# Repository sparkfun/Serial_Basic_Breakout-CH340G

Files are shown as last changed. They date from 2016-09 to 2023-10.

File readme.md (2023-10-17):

SparkFun Serial Basic Breakout - CH340G
========================================

SparkFun Serial Basic Breakout - CH340G

[*SparkFun Serial Basic Breakout - CH340G (DEV-14050)*](https://www.sparkfun.com/products/14050)

This is a CH340G based board that converts USB to Serial. 
It follows the standard Arduino pin out so this can be used to program the Pro and Pro Mini line of Arduinos. 
It can also be used as a general serial device for debugging (such as with a GPS module).

Board is default 3.3V output and 3.3V serial signals but cutting the trace on the back of the board and 
soldering a jumper to 5V changes the VCC pin to output 5V and changes serial comm signals to 5V.

Repository Contents
-------------------

* **/Hardware** - Eagle design files (.brd, .sch)
* **/Production** - Production panel files (.brd)

Documentation
--------------
* **[Hookup Guide](https://learn.sparkfun.com/tutorials/serial-basic-hookup-guide)** - Basic hookup guide
* **[How to Install CH340 Drivers](https://www.sparkfun.com/ch340)** - Drivers if you need
* **[SparkFun Fritzing repo](https://github.com/sparkfun/Fritzing_Parts/blob/main/products/14050_sfe_serial_basic_breakout_ch340g.fzpz)** - Fritzing diagrams for SparkFun products.
* **[SparkFun 3D Model repo](https://github.com/sparkfun/3D_Models)** - 3D models of SparkFun products. 
* **[SparkFun Graphical Datasheets](https://github.com/sparkfun/Graphical_Datasheets)** -Graphical Datasheets for various SparkFun products.

License Information
-------------------

This product is _**open source**_! 

Please review the LICENSE.md file for license information. 

If you have any questions or concerns on licensing, please contact techsupport@sparkfun.com.

Distributed as-is; no warranty is given.

- Your friends at SparkFun.

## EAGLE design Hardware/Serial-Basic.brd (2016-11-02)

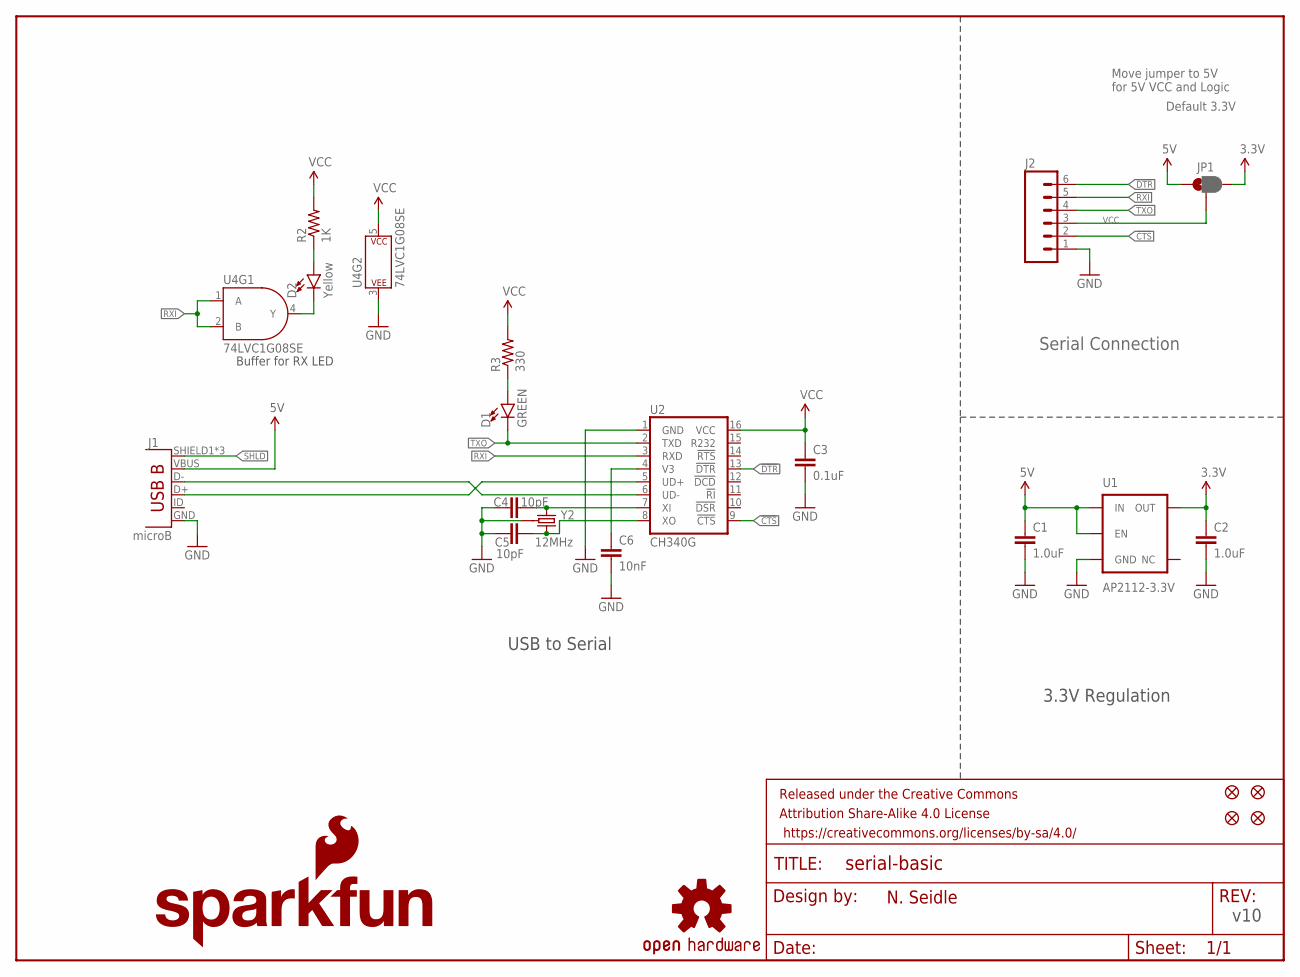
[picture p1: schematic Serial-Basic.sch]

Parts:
C1, C2: 1.0uF; 0603-CAP
C3: 0.1uF; 0603-CAP
C4, C5: 10pF; 0603-CAP
C6: 10nF; 0603-CAP
D1: GREEN; LED-0603
D2: Yellow; LED-0603
FRAME1: FRAME-LETTER; CREATIVE_COMMONS
J1: microB; USB-B-MICRO-SMD_V03
J2: M06SMD-FEMALE-V2; 1X06-SMD-FEMALE-V2
JP1: JUMPER-PAD-3-2OF3_NC_BY_PASTE; PAD-JUMPER-3-2OF3_NC_BY_PASTE_YES_SILK_FULL_BOX
JP3, JP4, JP5, JP6: FIDUCIAL1X2; FIDUCIAL-1X2
LOGO1: OSHW-LOGOS; OSHW-LOGO-S
LOGO2: SFE_LOGO_FLAME.1_INCH; SFE_LOGO_FLAME_.1
LOGO3: SFE_LOGO_NAME.1_INCH; SFE_LOGO_NAME_.1
R2: 1K; 0603-RES
R3: 330; 0603-RES
U1: AP2112-3.3V; SOT23-5
U2: CH340G; SO016
U4: 74LVC1G08SE; SOT353
Y2: 12MHz; CRYSTAL-SMD-3.2X2.5

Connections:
3.3V: C2.1, JP1.3, U1.5 (OUT)
5V: C1.1, J1.VBUS, JP1.1, U1.1 (IN), U1.3 (EN)
!CTS: J2.2, U2.9 (!CTS)
!DTR: J2.6, U2.13 (!DTR)
GND: C1.2, C2.2, C3.2, C4.1, C5.1, C6.2, J1.GND, J2.1, U1.2 (GND), U2.1 (GND), U4.3 (P$V-), Y2.2 (GND), Y2.4 (GND)
unnamed: D1.A, R3.1
unnamed: D2.A, R2.1
unnamed: C5.2, U2.8 (XO), Y2.3 (2)
unnamed: C4.2, U2.7 (XI), Y2.1
unnamed: D2.C, U4.4 (Y)
unnamed: J1.D-, U2.6 (UD-)
unnamed: J1.D+, U2.5 (UD+)
RXI: J2.5, U2.3 (RXD), U4.1 (A), U4.2 (B)
SHLD: J1.SHIELD1 (SHIELD), J1.SHIELD2 (SHIELD), J1.SHIELD3 (SHIELD)
TXO: D1.C, J2.4, U2.2 (TXD)
V3: C6.1, U2.4 (V3)
VCC: C3.1, J2.3, JP1.2, R2.2, R3.2, U2.16 (VCC), U4.5 (P$V+)

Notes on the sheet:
Default 3.3V
v10
USB to Serial
3.3V Regulation
N. Seidle
Move jumper to 5V for 5V VCC and Logic
Buffer for RX LED
Serial Connection

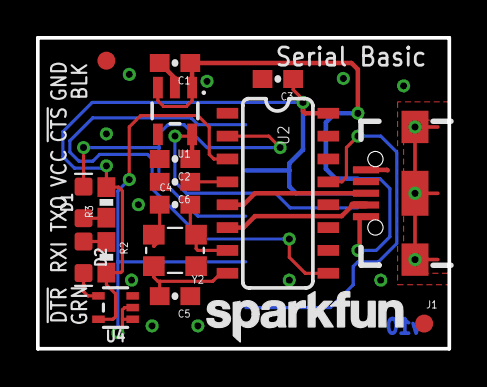
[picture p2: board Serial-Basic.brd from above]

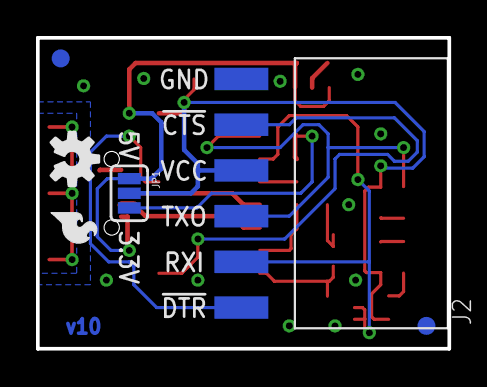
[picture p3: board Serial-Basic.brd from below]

Board: 2 copper layers, 22.9 x 17.3 mm, 25 parts (6 on the bottom side), 17 nets.

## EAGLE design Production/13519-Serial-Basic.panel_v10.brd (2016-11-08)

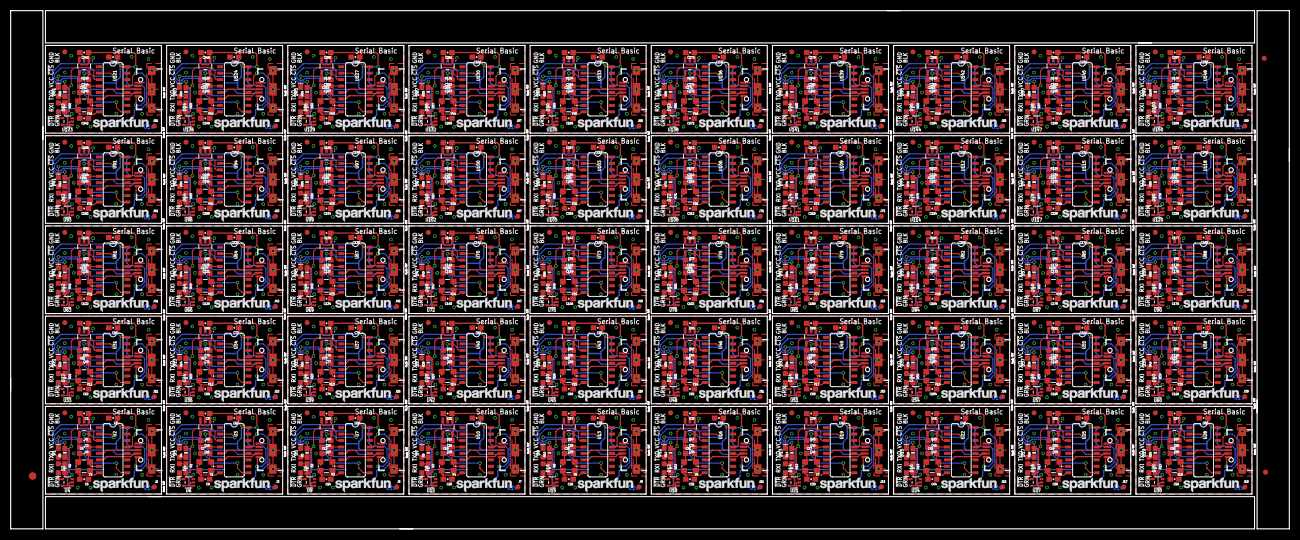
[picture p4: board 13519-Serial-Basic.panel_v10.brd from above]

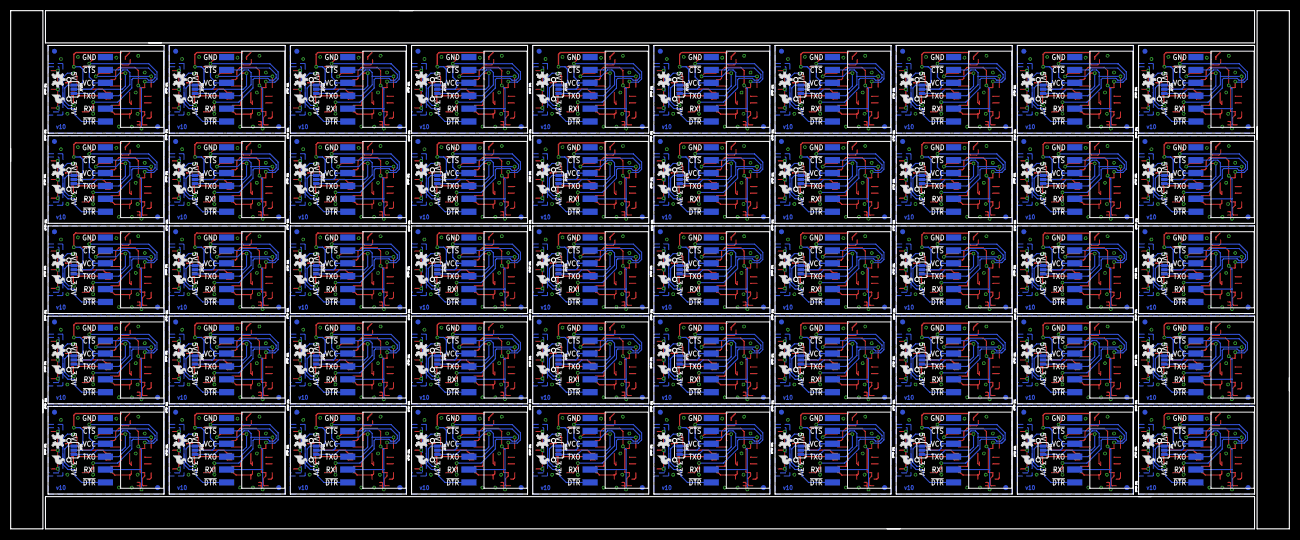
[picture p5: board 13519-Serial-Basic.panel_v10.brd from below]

Board: 2 copper layers, 252.0 x 102.1 mm, 1203 parts (300 on the bottom side), 850 nets.

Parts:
C1, C2, C9, C10, C15, C16, C21, C22, C27, C28, C33, C34, C39, C40, C45, C46, C51, C52, C57, C58, C63, C64, C69, C70, C75, C76, C81, C82, C87, C88, C93, C94, C99, C100, C105, C106, C111, C112, C117, C118, C123, C124, C129, C130, C135, C136, C141, C142, C147, C148, C153, C154, C159, C160, C165, C166, C171, C172, C177, C178, C183, C184, C189, C190, C195, C196, C201, C202, C207, C208, C213, C214, C219, C220, C225, C226, C231, C232, C237, C238, C243, C244, C249, C250, C255, C256, C261, C262, C267, C268, C273, C274, C279, C280, C285, C286, C291, C292, C297, C298: 1.0uF; 0603-CAP
C3, C12, C18, C24, C30, C36, C42, C48, C54, C60, C66, C72, C78, C84, C90, C96, C102, C108, C114, C120, C126, C132, C138, C144, C150, C156, C162, C168, C174, C180, C186, C192, C198, C204, C210, C216, C222, C228, C234, C240, C246, C252, C258, C264, C270, C276, C282, C288, C294, C300: 0.1uF; 0603-CAP
C4, C5, C7, C8, C13, C14, C19, C20, C25, C26, C31, C32, C37, C38, C43, C44, C49, C50, C55, C56, C61, C62, C67, C68, C73, C74, C79, C80, C85, C86, C91, C92, C97, C98, C103, C104, C109, C110, C115, C116, C121, C122, C127, C128, C133, C134, C139, C140, C145, C146, C151, C152, C157, C158, C163, C164, C169, C170, C175, C176, C181, C182, C187, C188, C193, C194, C199, C200, C205, C206, C211, C212, C217, C218, C223, C224, C229, C230, C235, C236, C241, C242, C247, C248, C253, C254, C259, C260, C265, C266, C271, C272, C277, C278, C283, C284, C289, C290, C295, C296: 10pF; 0603-CAP
C6, C11, C17, C23, C29, C35, C41, C47, C53, C59, C65, C71, C77, C83, C89, C95, C101, C107, C113, C119, C125, C131, C137, C143, C149, C155, C161, C167, C173, C179, C185, C191, C197, C203, C209, C215, C221, C227, C233, C239, C245, C251, C257, C263, C269, C275, C281, C287, C293, C299: 10nF; 0603-CAP
D1, D3, D5, D7, D9, D11, D13, D15, D17, D19, D21, D23, D25, D27, D29, D31, D33, D35, D37, D39, D41, D43, D45, D47, D49, D51, D53, D55, D57, D59, D61, D63, D65, D67, D69, D71, D73, D75, D77, D79, D81, D83, D85, D87, D89, D91, D93, D95, D97, D99: GREEN; LED-0603
D2, D4, D6, D8, D10, D12, D14, D16, D18, D20, D22, D24, D26, D28, D30, D32, D34, D36, D38, D40, D42, D44, D46, D48, D50, D52, D54, D56, D58, D60, D62, D64, D66, D68, D70, D72, D74, D76, D78, D80, D82, D84, D86, D88, D90, D92, D94, D96, D98, D100: Yellow; LED-0603
E$1: FIDUCIAL-1.5X3
E$5, E$6: FIDUCIAL-1X2
J1, J3, J5, J7, J9, J11, J13, J15, J17, J19, J21, J23, J25, J27, J29, J31, J33, J35, J37, J39, J41, J43, J45, J47, J49, J51, J53, J55, J57, J59, J61, J63, J65, J67, J69, J71, J73, J75, J77, J79, J81, J83, J85, J87, J89, J91, J93, J95, J97, J99: microB; USB-B-MICRO-SMD_V03
J2, J4, J6, J8, J10, J12, J14, J16, J18, J20, J22, J24, J26, J28, J30, J32, J34, J36, J38, J40, J42, J44, J46, J48, J50, J52, J54, J56, J58, J60, J62, J64, J66, J68, J70, J72, J74, J76, J78, J80, J82, J84, J86, J88, J90, J92, J94, J96, J98, J100: 1X06-SMD-FEMALE-V2
JP1, JP10, JP15, JP20, JP25, JP30, JP35, JP40, JP45, JP50, JP55, JP60, JP65, JP70, JP75, JP80, JP85, JP90, JP95, JP100, JP105, JP110, JP115, JP120, JP125, JP130, JP135, JP140, JP145, JP150, JP155, JP160, JP165, JP170, JP175, JP180, JP185, JP190, JP195, JP200, JP205, JP210, JP215, JP220, JP225, JP230, JP235, JP240, JP245, JP250: PAD-JUMPER-3-2OF3_NC_BY_PASTE_YES_SILK_FULL_BOX
JP2, JP3, JP4, JP5, JP6, JP7, JP8, JP9, JP11, JP12, JP13, JP14, JP16, JP17, JP18, JP19, JP21, JP22, JP23, JP24, JP26, JP27, JP28, JP29, JP31, JP32, JP33, JP34, JP36, JP37, JP38, JP39, JP41, JP42, JP43, JP44, JP46, JP47, JP48, JP49, JP51, JP52, JP53, JP54, JP56, JP57, JP58, JP59, JP61, JP62, JP63, JP64, JP66, JP67, JP68, JP69, JP71, JP72, JP73, JP74, JP76, JP77, JP78, JP79, JP81, JP82, JP83, JP84, JP86, JP87, JP88, JP89, JP91, JP92, JP93, JP94, JP96, JP97, JP98, JP99, JP101, JP102, JP103, JP104, JP106, JP107, JP108, JP109, JP111, JP112, JP113, JP114, JP116, JP117, JP118, JP119, JP121, JP122, JP123, JP124, JP126, JP127, JP128, JP129, JP131, JP132, JP133, JP134, JP136, JP137, JP138, JP139, JP141, JP142, JP143, JP144, JP146, JP147, JP148, JP149, JP151, JP152, JP153, JP154, JP156, JP157, JP158, JP159, JP161, JP162, JP163, JP164, JP166, JP167, JP168, JP169, JP171, JP172, JP173, JP174, JP176, JP177, JP178, JP179, JP181, JP182, JP183, JP184, JP186, JP187, JP188, JP189, JP191, JP192, JP193, JP194, JP196, JP197, JP198, JP199, JP201, JP202, JP203, JP204, JP206, JP207, JP208, JP209, JP211, JP212, JP213, JP214, JP216, JP217, JP218, JP219, JP221, JP222, JP223, JP224, JP226, JP227, JP228, JP229, JP231, JP232, JP233, JP234, JP236, JP237, JP238, JP239, JP241, JP242, JP243, JP244, JP246, JP247, JP248, JP249: FIDUCIAL1X2; FIDUCIAL-1X2
LOGO1, LOGO4, LOGO7, LOGO10, LOGO13, LOGO16, LOGO19, LOGO22, LOGO25, LOGO28, LOGO31, LOGO34, LOGO37, LOGO40, LOGO43, LOGO46, LOGO49, LOGO52, LOGO55, LOGO58, LOGO61, LOGO64, LOGO67, LOGO70, LOGO73, LOGO76, LOGO79, LOGO82, LOGO85, LOGO88, LOGO91, LOGO94, LOGO97, LOGO100, LOGO103, LOGO106, LOGO109, LOGO112, LOGO115, LOGO118, LOGO121, LOGO124, LOGO127, LOGO130, LOGO133, LOGO136, LOGO139, LOGO142, LOGO145, LOGO148: OSHW-LOGOS; OSHW-LOGO-S
LOGO2, LOGO6, LOGO9, LOGO12, LOGO15, LOGO18, LOGO21, LOGO24, LOGO27, LOGO30, LOGO33, LOGO36, LOGO39, LOGO42, LOGO45, LOGO48, LOGO51, LOGO54, LOGO57, LOGO60, LOGO63, LOGO66, LOGO69, LOGO72, LOGO75, LOGO78, LOGO81, LOGO84, LOGO87, LOGO90, LOGO93, LOGO96, LOGO99, LOGO102, LOGO105, LOGO108, LOGO111, LOGO114, LOGO117, LOGO120, LOGO123, LOGO126, LOGO129, LOGO132, LOGO135, LOGO138, LOGO141, LOGO144, LOGO147, LOGO150: SFE_LOGO_FLAME.1_INCH; SFE_LOGO_FLAME_.1
LOGO3, LOGO5, LOGO8, LOGO11, LOGO14, LOGO17, LOGO20, LOGO23, LOGO26, LOGO29, LOGO32, LOGO35, LOGO38, LOGO41, LOGO44, LOGO47, LOGO50, LOGO53, LOGO56, LOGO59, LOGO62, LOGO65, LOGO68, LOGO71, LOGO74, LOGO77, LOGO80, LOGO83, LOGO86, LOGO89, LOGO92, LOGO95, LOGO98, LOGO101, LOGO104, LOGO107, LOGO110, LOGO113, LOGO116, LOGO119, LOGO122, LOGO125, LOGO128, LOGO131, LOGO134, LOGO137, LOGO140, LOGO143, LOGO146, LOGO149: SFE_LOGO_NAME.1_INCH; SFE_LOGO_NAME_.1
R1, R2, R5, R7, R9, R11, R13, R15, R17, R19, R21, R23, R25, R27, R29, R31, R33, R35, R37, R39, R41, R43, R45, R47, R49, R51, R53, R55, R57, R59, R61, R63, R65, R67, R69, R71, R73, R75, R77, R79, R81, R83, R85, R87, R89, R91, R93, R95, R97, R99: 1K; 0603-RES
R3, R4, R6, R8, R10, R12, R14, R16, R18, R20, R22, R24, R26, R28, R30, R32, R34, R36, R38, R40, R42, R44, R46, R48, R50, R52, R54, R56, R58, R60, R62, R64, R66, R68, R70, R72, R74, R76, R78, R80, R82, R84, R86, R88, R90, R92, R94, R96, R98, R100: 330; 0603-RES
U1, U5, U8, U11, U14, U17, U20, U23, U26, U29, U32, U35, U38, U41, U44, U47, U50, U53, U56, U59, U62, U65, U68, U71, U74, U77, U80, U83, U86, U89, U92, U95, U98, U101, U104, U107, U110, U113, U116, U119, U122, U125, U128, U131, U134, U137, U140, U143, U146, U149: AP2112-3.3V; SOT23-5
U2, U3, U7, U10, U13, U16, U19, U22, U25, U28, U31, U34, U37, U40, U43, U46, U49, U52, U55, U58, U61, U64, U67, U70, U73, U76, U79, U82, U85, U88, U91, U94, U97, U100, U103, U106, U109, U112, U115, U118, U121, U124, U127, U130, U133, U136, U139, U142, U145, U148: CH340G; SO016
U4, U6, U9, U12, U15, U18, U21, U24, U27, U30, U33, U36, U39, U42, U45, U48, U51, U54, U57, U60, U63, U66, U69, U72, U75, U78, U81, U84, U87, U90, U93, U96, U99, U102, U105, U108, U111, U114, U117, U120, U123, U126, U129, U132, U135, U138, U141, U144, U147, U150: 74LVC1G08SE; SOT353
Y1, Y2, Y3, Y4, Y5, Y6, Y7, Y8, Y9, Y10, Y11, Y12, Y13, Y14, Y15, Y16, Y17, Y18, Y19, Y20, Y21, Y22, Y23, Y24, Y25, Y26, Y27, Y28, Y29, Y30, Y31, Y32, Y33, Y34, Y35, Y36, Y37, Y38, Y39, Y40, Y41, Y42, Y43, Y44, Y45, Y46, Y47, Y48, Y49, Y50: 12MHz; CRYSTAL-SMD-3.2X2.5

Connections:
3.3V: C2.1, JP1.3, U1.5
3.3V1: C10.1, JP10.3, U5.5
3.3V2: C16.1, JP15.3, U8.5
3.3V3: C22.1, JP20.3, U11.5
3.3V4: C28.1, JP25.3, U14.5
3.3V5: C34.1, JP30.3, U17.5
3.3V6: C40.1, JP35.3, U20.5
3.3V7: C46.1, JP40.3, U23.5
3.3V8: C52.1, JP45.3, U26.5
3.3V9: C58.1, JP50.3, U29.5
3.3V10: C64.1, JP55.3, U32.5
3.3V11: C70.1, JP60.3, U35.5
3.3V12: C76.1, JP65.3, U38.5
3.3V13: C82.1, JP70.3, U41.5
3.3V14: C88.1, JP75.3, U44.5
3.3V15: C94.1, JP80.3, U47.5
3.3V16: C100.1, JP85.3, U50.5
3.3V17: C106.1, JP90.3, U53.5
3.3V18: C112.1, JP95.3, U56.5
3.3V19: C118.1, JP100.3, U59.5
3.3V20: C124.1, JP105.3, U62.5
3.3V21: C130.1, JP110.3, U65.5
3.3V22: C136.1, JP115.3, U68.5
3.3V23: C142.1, JP120.3, U71.5
3.3V24: C148.1, JP125.3, U74.5
3.3V25: C154.1, JP130.3, U77.5
3.3V26: C160.1, JP135.3, U80.5
3.3V27: C166.1, JP140.3, U83.5
3.3V28: C172.1, JP145.3, U86.5
3.3V29: C178.1, JP150.3, U89.5
3.3V30: C184.1, JP155.3, U92.5
3.3V31: C190.1, JP160.3, U95.5
3.3V32: C196.1, JP165.3, U98.5
3.3V33: C202.1, JP170.3, U101.5
3.3V34: C208.1, JP175.3, U104.5
3.3V35: C214.1, JP180.3, U107.5
3.3V36: C220.1, JP185.3, U110.5
3.3V37: C226.1, JP190.3, U113.5
3.3V38: C232.1, JP195.3, U116.5
3.3V39: C238.1, JP200.3, U119.5
3.3V40: C244.1, JP205.3, U122.5
3.3V41: C250.1, JP210.3, U125.5
3.3V42: C256.1, JP215.3, U128.5
3.3V43: C262.1, JP220.3, U131.5
3.3V44: C268.1, JP225.3, U134.5
3.3V45: C274.1, JP230.3, U137.5
3.3V46: C280.1, JP235.3, U140.5
3.3V47: C286.1, JP240.3, U143.5
3.3V48: C292.1, JP245.3, U146.5
3.3V49: C298.1, JP250.3, U149.5
5V: C1.1, J1.VBUS, JP1.1, U1.1, U1.3
5V1: C9.1, J3.VBUS, JP10.1, U5.1, U5.3
5V2: C15.1, J5.VBUS, JP15.1, U8.1, U8.3
5V3: C21.1, J7.VBUS, JP20.1, U11.1, U11.3
5V4: C27.1, J9.VBUS, JP25.1, U14.1, U14.3
5V5: C33.1, J11.VBUS, JP30.1, U17.1, U17.3
5V6: C39.1, J13.VBUS, JP35.1, U20.1, U20.3
5V7: C45.1, J15.VBUS, JP40.1, U23.1, U23.3
5V8: C51.1, J17.VBUS, JP45.1, U26.1, U26.3
5V9: C57.1, J19.VBUS, JP50.1, U29.1, U29.3
5V10: C63.1, J21.VBUS, JP55.1, U32.1, U32.3
5V11: C69.1, J23.VBUS, JP60.1, U35.1, U35.3
5V12: C75.1, J25.VBUS, JP65.1, U38.1, U38.3
5V13: C81.1, J27.VBUS, JP70.1, U41.1, U41.3
5V14: C87.1, J29.VBUS, JP75.1, U44.1, U44.3
5V15: C93.1, J31.VBUS, JP80.1, U47.1, U47.3
5V16: C99.1, J33.VBUS, JP85.1, U50.1, U50.3
5V17: C105.1, J35.VBUS, JP90.1, U53.1, U53.3
5V18: C111.1, J37.VBUS, JP95.1, U56.1, U56.3
5V19: C117.1, J39.VBUS, JP100.1, U59.1, U59.3
5V20: C123.1, J41.VBUS, JP105.1, U62.1, U62.3
5V21: C129.1, J43.VBUS, JP110.1, U65.1, U65.3
5V22: C135.1, J45.VBUS, JP115.1, U68.1, U68.3
5V23: C141.1, J47.VBUS, JP120.1, U71.1, U71.3
5V24: C147.1, J49.VBUS, JP125.1, U74.1, U74.3
5V25: C153.1, J51.VBUS, JP130.1, U77.1, U77.3
5V26: C159.1, J53.VBUS, JP135.1, U80.1, U80.3
5V27: C165.1, J55.VBUS, JP140.1, U83.1, U83.3
5V28: C171.1, J57.VBUS, JP145.1, U86.1, U86.3
5V29: C177.1, J59.VBUS, JP150.1, U89.1, U89.3
5V30: C183.1, J61.VBUS, JP155.1, U92.1, U92.3
5V31: C189.1, J63.VBUS, JP160.1, U95.1, U95.3
5V32: C195.1, J65.VBUS, JP165.1, U98.1, U98.3
5V33: C201.1, J67.VBUS, JP170.1, U101.1, U101.3
5V34: C207.1, J69.VBUS, JP175.1, U104.1, U104.3
5V35: C213.1, J71.VBUS, JP180.1, U107.1, U107.3
5V36: C219.1, J73.VBUS, JP185.1, U110.1, U110.3
5V37: C225.1, J75.VBUS, JP190.1, U113.1, U113.3
5V38: C231.1, J77.VBUS, JP195.1, U116.1, U116.3
5V39: C237.1, J79.VBUS, JP200.1, U119.1, U119.3
5V40: C243.1, J81.VBUS, JP205.1, U122.1, U122.3
5V41: C249.1, J83.VBUS, JP210.1, U125.1, U125.3
5V42: C255.1, J85.VBUS, JP215.1, U128.1, U128.3
5V43: C261.1, J87.VBUS, JP220.1, U131.1, U131.3
5V44: C267.1, J89.VBUS, JP225.1, U134.1, U134.3
5V45: C273.1, J91.VBUS, JP230.1, U137.1, U137.3
5V46: C279.1, J93.VBUS, JP235.1, U140.1, U140.3
5V47: C285.1, J95.VBUS, JP240.1, U143.1, U143.3
5V48: C291.1, J97.VBUS, JP245.1, U146.1, U146.3
5V49: C297.1, J99.VBUS, JP250.1, U149.1, U149.3
!CTS: J2.2, U2.9
!CTS1: J4.2, U3.9
!CTS2: J6.2, U7.9
!CTS3: J8.2, U10.9
!CTS4: J10.2, U13.9
!CTS5: J12.2, U16.9
!CTS6: J14.2, U19.9
!CTS7: J16.2, U22.9
!CTS8: J18.2, U25.9
!CTS9: J20.2, U28.9
!CTS10: J22.2, U31.9
!CTS11: J24.2, U34.9
!CTS12: J26.2, U37.9
!CTS13: J28.2, U40.9
!CTS14: J30.2, U43.9
!CTS15: J32.2, U46.9
!CTS16: J34.2, U49.9
!CTS17: J36.2, U52.9
!CTS18: J38.2, U55.9
!CTS19: J40.2, U58.9
!CTS20: J42.2, U61.9
!CTS21: J44.2, U64.9
!CTS22: J46.2, U67.9
!CTS23: J48.2, U70.9
!CTS24: J50.2, U73.9
!CTS25: J52.2, U76.9
!CTS26: J54.2, U79.9
!CTS27: J56.2, U82.9
!CTS28: J58.2, U85.9
!CTS29: J60.2, U88.9
!CTS30: J62.2, U91.9
!CTS31: J64.2, U94.9
!CTS32: J66.2, U97.9
!CTS33: J68.2, U100.9
!CTS34: J70.2, U103.9
!CTS35: J72.2, U106.9
!CTS36: J74.2, U109.9
!CTS37: J76.2, U112.9
!CTS38: J78.2, U115.9
!CTS39: J80.2, U118.9
!CTS40: J82.2, U121.9
!CTS41: J84.2, U124.9
!CTS42: J86.2, U127.9
!CTS43: J88.2, U130.9
!CTS44: J90.2, U133.9
!CTS45: J92.2, U136.9
!CTS46: J94.2, U139.9
!CTS47: J96.2, U142.9
!CTS48: J98.2, U145.9
!CTS49: J100.2, U148.9
!DTR: J2.6, U2.13
!DTR1: J4.6, U3.13
!DTR2: J6.6, U7.13
!DTR3: J8.6, U10.13
!DTR4: J10.6, U13.13
!DTR5: J12.6, U16.13
!DTR6: J14.6, U19.13
!DTR7: J16.6, U22.13
!DTR8: J18.6, U25.13
!DTR9: J20.6, U28.13
!DTR10: J22.6, U31.13
!DTR11: J24.6, U34.13
!DTR12: J26.6, U37.13
!DTR13: J28.6, U40.13
!DTR14: J30.6, U43.13
!DTR15: J32.6, U46.13
!DTR16: J34.6, U49.13
!DTR17: J36.6, U52.13
!DTR18: J38.6, U55.13
!DTR19: J40.6, U58.13
!DTR20: J42.6, U61.13
!DTR21: J44.6, U64.13
!DTR22: J46.6, U67.13
!DTR23: J48.6, U70.13
!DTR24: J50.6, U73.13
!DTR25: J52.6, U76.13
!DTR26: J54.6, U79.13
!DTR27: J56.6, U82.13
!DTR28: J58.6, U85.13
!DTR29: J60.6, U88.13
!DTR30: J62.6, U91.13
!DTR31: J64.6, U94.13
!DTR32: J66.6, U97.13
!DTR33: J68.6, U100.13
!DTR34: J70.6, U103.13
!DTR35: J72.6, U106.13
!DTR36: J74.6, U109.13
!DTR37: J76.6, U112.13
!DTR38: J78.6, U115.13
!DTR39: J80.6, U118.13
!DTR40: J82.6, U121.13
!DTR41: J84.6, U124.13
!DTR42: J86.6, U127.13
!DTR43: J88.6, U130.13
!DTR44: J90.6, U133.13
!DTR45: J92.6, U136.13
!DTR46: J94.6, U139.13
!DTR47: J96.6, U142.13
!DTR48: J98.6, U145.13
!DTR49: J100.6, U148.13
GND: C1.2, C2.2, C3.2, C4.1, C5.1, C6.2, J1.GND, J2.1, U1.2, U2.1, U4.3, Y2.2, Y2.4
GND1: C7.1, C8.1, C9.2, C10.2, C11.2, C12.2, J3.GND, J4.1, U3.1, U5.2, U6.3, Y1.2, Y1.4
GND2: C13.1, C14.1, C15.2, C16.2, C17.2, C18.2, J5.GND, J6.1, U7.1, U8.2, U9.3, Y3.2, Y3.4
GND3: C19.1, C20.1, C21.2, C22.2, C23.2, C24.2, J7.GND, J8.1, U10.1, U11.2, U12.3, Y4.2, Y4.4
GND4: C25.1, C26.1, C27.2, C28.2, C29.2, C30.2, J9.GND, J10.1, U13.1, U14.2, U15.3, Y5.2, Y5.4
GND5: C31.1, C32.1, C33.2, C34.2, C35.2, C36.2, J11.GND, J12.1, U16.1, U17.2, U18.3, Y6.2, Y6.4
GND6: C37.1, C38.1, C39.2, C40.2, C41.2, C42.2, J13.GND, J14.1, U19.1, U20.2, U21.3, Y7.2, Y7.4
GND7: C43.1, C44.1, C45.2, C46.2, C47.2, C48.2, J15.GND, J16.1, U22.1, U23.2, U24.3, Y8.2, Y8.4
GND8: C49.1, C50.1, C51.2, C52.2, C53.2, C54.2, J17.GND, J18.1, U25.1, U26.2, U27.3, Y9.2, Y9.4
GND9: C55.1, C56.1, C57.2, C58.2, C59.2, C60.2, J19.GND, J20.1, U28.1, U29.2, U30.3, Y10.2, Y10.4
GND10: C61.1, C62.1, C63.2, C64.2, C65.2, C66.2, J21.GND, J22.1, U31.1, U32.2, U33.3, Y11.2, Y11.4
GND11: C67.1, C68.1, C69.2, C70.2, C71.2, C72.2, J23.GND, J24.1, U34.1, U35.2, U36.3, Y12.2, Y12.4
GND12: C73.1, C74.1, C75.2, C76.2, C77.2, C78.2, J25.GND, J26.1, U37.1, U38.2, U39.3, Y13.2, Y13.4
GND13: C79.1, C80.1, C81.2, C82.2, C83.2, C84.2, J27.GND, J28.1, U40.1, U41.2, U42.3, Y14.2, Y14.4
GND14: C85.1, C86.1, C87.2, C88.2, C89.2, C90.2, J29.GND, J30.1, U43.1, U44.2, U45.3, Y15.2, Y15.4
GND15: C91.1, C92.1, C93.2, C94.2, C95.2, C96.2, J31.GND, J32.1, U46.1, U47.2, U48.3, Y16.2, Y16.4
GND16: C97.1, C98.1, C99.2, C100.2, C101.2, C102.2, J33.GND, J34.1, U49.1, U50.2, U51.3, Y17.2, Y17.4
GND17: C103.1, C104.1, C105.2, C106.2, C107.2, C108.2, J35.GND, J36.1, U52.1, U53.2, U54.3, Y18.2, Y18.4
GND18: C109.1, C110.1, C111.2, C112.2, C113.2, C114.2, J37.GND, J38.1, U55.1, U56.2, U57.3, Y19.2, Y19.4
GND19: C115.1, C116.1, C117.2, C118.2, C119.2, C120.2, J39.GND, J40.1, U58.1, U59.2, U60.3, Y20.2, Y20.4
GND20: C121.1, C122.1, C123.2, C124.2, C125.2, C126.2, J41.GND, J42.1, U61.1, U62.2, U63.3, Y21.2, Y21.4
GND21: C127.1, C128.1, C129.2, C130.2, C131.2, C132.2, J43.GND, J44.1, U64.1, U65.2, U66.3, Y22.2, Y22.4
GND22: C133.1, C134.1, C135.2, C136.2, C137.2, C138.2, J45.GND, J46.1, U67.1, U68.2, U69.3, Y23.2, Y23.4
GND23: C139.1, C140.1, C141.2, C142.2, C143.2, C144.2, J47.GND, J48.1, U70.1, U71.2, U72.3, Y24.2, Y24.4
GND24: C145.1, C146.1, C147.2, C148.2, C149.2, C150.2, J49.GND, J50.1, U73.1, U74.2, U75.3, Y25.2, Y25.4
GND25: C151.1, C152.1, C153.2, C154.2, C155.2, C156.2, J51.GND, J52.1, U76.1, U77.2, U78.3, Y26.2, Y26.4
GND26: C157.1, C158.1, C159.2, C160.2, C161.2, C162.2, J53.GND, J54.1, U79.1, U80.2, U81.3, Y27.2, Y27.4
GND27: C163.1, C164.1, C165.2, C166.2, C167.2, C168.2, J55.GND, J56.1, U82.1, U83.2, U84.3, Y28.2, Y28.4
GND28: C169.1, C170.1, C171.2, C172.2, C173.2, C174.2, J57.GND, J58.1, U85.1, U86.2, U87.3, Y29.2, Y29.4
GND29: C175.1, C176.1, C177.2, C178.2, C179.2, C180.2, J59.GND, J60.1, U88.1, U89.2, U90.3, Y30.2, Y30.4
GND30: C181.1, C182.1, C183.2, C184.2, C185.2, C186.2, J61.GND, J62.1, U91.1, U92.2, U93.3, Y31.2, Y31.4
GND31: C187.1, C188.1, C189.2, C190.2, C191.2, C192.2, J63.GND, J64.1, U94.1, U95.2, U96.3, Y32.2, Y32.4
GND32: C193.1, C194.1, C195.2, C196.2, C197.2, C198.2, J65.GND, J66.1, U97.1, U98.2, U99.3, Y33.2, Y33.4
GND33: C199.1, C200.1, C201.2, C202.2, C203.2, C204.2, J67.GND, J68.1, U100.1, U101.2, U102.3, Y34.2, Y34.4
GND34: C205.1, C206.1, C207.2, C208.2, C209.2, C210.2, J69.GND, J70.1, U103.1, U104.2, U105.3, Y35.2, Y35.4
GND35: C211.1, C212.1, C213.2, C214.2, C215.2, C216.2, J71.GND, J72.1, U106.1, U107.2, U108.3, Y36.2, Y36.4
GND36: C217.1, C218.1, C219.2, C220.2, C221.2, C222.2, J73.GND, J74.1, U109.1, U110.2, U111.3, Y37.2, Y37.4
GND37: C223.1, C224.1, C225.2, C226.2, C227.2, C228.2, J75.GND, J76.1, U112.1, U113.2, U114.3, Y38.2, Y38.4
GND38: C229.1, C230.1, C231.2, C232.2, C233.2, C234.2, J77.GND, J78.1, U115.1, U116.2, U117.3, Y39.2, Y39.4
GND39: C235.1, C236.1, C237.2, C238.2, C239.2, C240.2, J79.GND, J80.1, U118.1, U119.2, U120.3, Y40.2, Y40.4
GND40: C241.1, C242.1, C243.2, C244.2, C245.2, C246.2, J81.GND, J82.1, U121.1, U122.2, U123.3, Y41.2, Y41.4
GND41: C247.1, C248.1, C249.2, C250.2, C251.2, C252.2, J83.GND, J84.1, U124.1, U125.2, U126.3, Y42.2, Y42.4
GND42: C253.1, C254.1, C255.2, C256.2, C257.2, C258.2, J85.GND, J86.1, U127.1, U128.2, U129.3, Y43.2, Y43.4
GND43: C259.1, C260.1, C261.2, C262.2, C263.2, C264.2, J87.GND, J88.1, U130.1, U131.2, U132.3, Y44.2, Y44.4
GND44: C265.1, C266.1, C267.2, C268.2, C269.2, C270.2, J89.GND, J90.1, U133.1, U134.2, U135.3, Y45.2, Y45.4
GND45: C271.1, C272.1, C273.2, C274.2, C275.2, C276.2, J91.GND, J92.1, U136.1, U137.2, U138.3, Y46.2, Y46.4
GND46: C277.1, C278.1, C279.2, C280.2, C281.2, C282.2, J93.GND, J94.1, U139.1, U140.2, U141.3, Y47.2, Y47.4
GND47: C283.1, C284.1, C285.2, C286.2, C287.2, C288.2, J95.GND, J96.1, U142.1, U143.2, U144.3, Y48.2, Y48.4
GND48: C289.1, C290.1, C291.2, C292.2, C293.2, C294.2, J97.GND, J98.1, U145.1, U146.2, U147.3, Y49.2, Y49.4
GND49: C295.1, C296.1, C297.2, C298.2, C299.2, C300.2, J99.GND, J100.1, U148.1, U149.2, U150.3, Y50.2, Y50.4
unnamed: D1.A, R3.1
unnamed: D2.A, R2.1
unnamed: C5.2, U2.8, Y2.3
unnamed: C4.2, U2.7, Y2.1
unnamed: D2.C, U4.4
unnamed: J1.D-, U2.6
unnamed: J1.D+, U2.5
unnamed: D3.A, R4.1
unnamed: D4.A, R1.1
unnamed: C8.2, U3.8, Y1.3
unnamed: C7.2, U3.7, Y1.1
unnamed: J3.D-, U3.6
unnamed: J3.D+, U3.5
unnamed: D4.C, U6.4
unnamed: D5.A, R6.1
unnamed: D6.A, R5.1
unnamed: C14.2, U7.8, Y3.3
unnamed: C13.2, U7.7, Y3.1
unnamed: J5.D-, U7.6
unnamed: J5.D+, U7.5
unnamed: D6.C, U9.4
unnamed: D7.A, R8.1
unnamed: D8.A, R7.1
unnamed: C20.2, U10.8, Y4.3
unnamed: C19.2, U10.7, Y4.1
unnamed: J7.D-, U10.6
unnamed: J7.D+, U10.5
unnamed: D8.C, U12.4
unnamed: D9.A, R10.1
unnamed: D10.A, R9.1
unnamed: C26.2, U13.8, Y5.3
unnamed: C25.2, U13.7, Y5.1
unnamed: J9.D-, U13.6
unnamed: J9.D+, U13.5
unnamed: D10.C, U15.4
unnamed: D11.A, R12.1
unnamed: D12.A, R11.1
unnamed: C32.2, U16.8, Y6.3
unnamed: C31.2, U16.7, Y6.1
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

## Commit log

2016-09-20 Initial PCB layout
    [CH340G Basic-5V.brd, CH340G Basic-5V.sch]
2016-09-20 Added TP to 3.3V. Passes checklist.
    [CH340G Basic-5V.brd, CH340G Basic-5V.sch]
2016-09-22 Many hardware changes from review.
    Moved 0.1uF closer to IC, changed to VCC net. Added via anchors to
    microB. Silk bumps. PCB width increase.
    [Serial-Basic.brd, Serial-Basic.sch]
2016-09-23 Fixing issues #1, #2, #3, #4
    [Serial-Basic.brd, Serial-Basic.sch]
2016-10-25 Changing resistor on Greeg LED to 330
    [Serial-Basic.brd, Serial-Basic.sch]
2016-10-25 Fixing DRC error
    [Serial-Basic.brd]
2016-11-01 Adding buffer to RX line.
    [Serial-Basic.brd, Serial-Basic.sch]
2016-11-02 Adding PROD_ID to AND gate
    [Serial-Basic.brd, Serial-Basic.sch]
2016-11-02 Add arrow to VCC net
    [Serial-Basic.sch]

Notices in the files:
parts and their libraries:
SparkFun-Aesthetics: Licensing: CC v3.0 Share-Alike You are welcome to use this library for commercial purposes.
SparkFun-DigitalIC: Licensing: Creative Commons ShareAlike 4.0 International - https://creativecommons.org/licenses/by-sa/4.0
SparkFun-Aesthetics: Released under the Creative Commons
